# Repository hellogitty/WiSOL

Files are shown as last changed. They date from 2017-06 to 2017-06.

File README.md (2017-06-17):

# WiSOL
Eagle Library, BoB and other moduls and (in near future) demo source codes for WiSOL Sigfox Modules (maybe other repo)

Welcome to the WiSOL Github page made by GREATECH GmbH to support the WSSFM10 Sigfox Modules by WiSOL.<br>
We like to add here (Eagle) CAD library, schematics (eg. BoB Module) and demo projects for different MCUs using the Sigfox modules.
The Library should be fine and ready for production use.
The BoB module is now all metric and vias moved to outside the WiSOL module, so under the module is no via left.
We think vias below the module should be no issue, but anyway.

For purchase you can request price at http://www.greatech.de or order by web shop (soon) http://syncronice.me/products/<br>
A more detailed Wiki we try to build here: http://sensoco.wikidot.com/start

WiSOL is a trademark by WiSOL South Korea<br>
GREATECH, Syncronice and Sensoco are trademark by GREATECH GmbH Germany

**GREATECH GmbH**<br>
Lindenstr. 66A<br>
45478 Mülheim an der Ruhr, Germany<br>
USt-ID-Nr.: 	DE230390597<br>
WEEE-Reg.-Nr.: 	DE 39441116<br>
E-Mail: 	info@greatech.de<br>
Telephone: 	+49 (0) 208 - 740 49 27 0<br>
Fax no.: 	+49 (0) 208 - 740 49 27 19<br>
http://www.greatech.de

**WiSOL**<br>
Company 	WISOL Corp<br>
Address 	531-7 Gijang-ro Osan-si Gyeonggi-do<br>
CEO 	 	Kim Ji Ho<br>
TEL 	 	070-7837-2730<br>
FAX 	 	031-378-6340<br>
http://www.wisol.co.kr/2016_company_eng/?ckattempt=1

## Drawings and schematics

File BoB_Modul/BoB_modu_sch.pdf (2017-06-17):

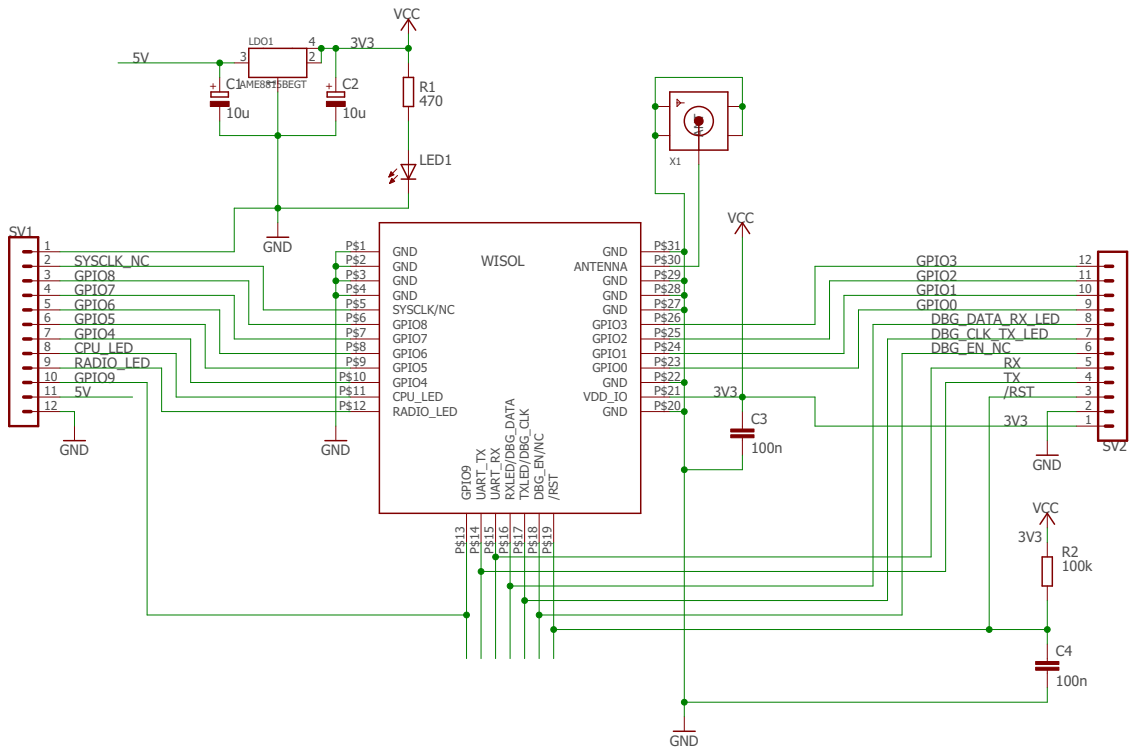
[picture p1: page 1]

P$2 | P$30 GND
P$3 | P$29 ANTENNA
P$4 | P$28 GND
P$5 | P$27 GND

GPIO4 P$10 | 3V3
P$11 | P$21 GND
P$12 | P$20 VDD_IO

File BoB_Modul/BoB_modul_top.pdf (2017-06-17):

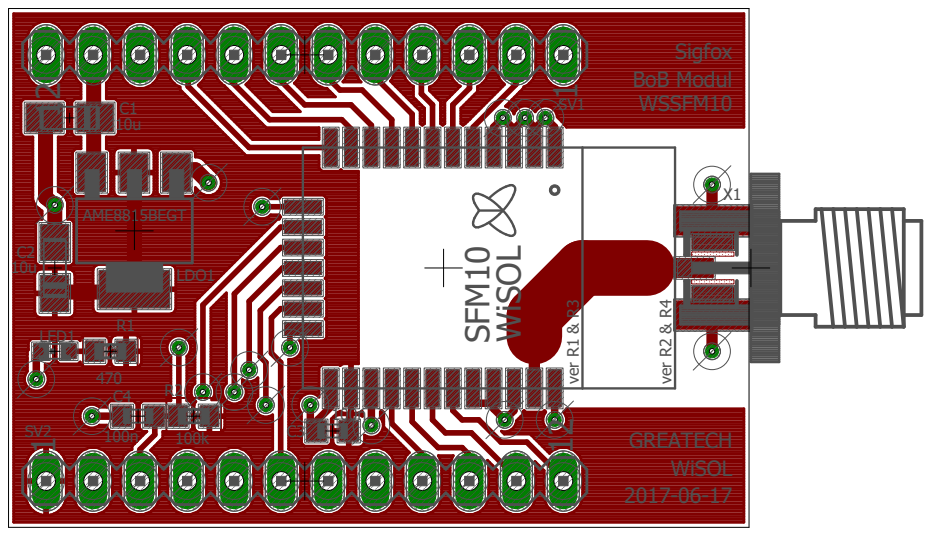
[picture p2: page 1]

WiSOL SFM10 ver R1 & R3 ver R2 & R4 112 112GREATECH Sigfox WiSOL WSSFM10 2017-06-17 BoB ModulX1 SV1 LDO1 C1 C2 R1 LED1 C3 C4 R2 SV2 AME8815BEGT 10u 10u 470 100n 100n 100k

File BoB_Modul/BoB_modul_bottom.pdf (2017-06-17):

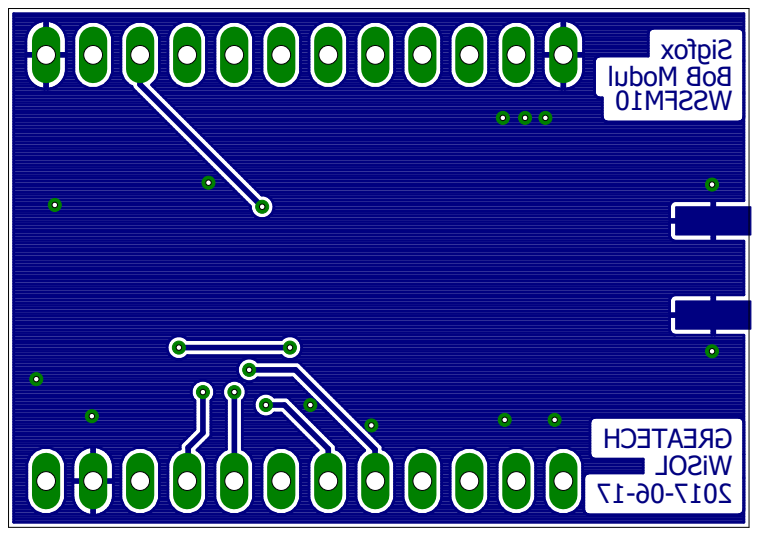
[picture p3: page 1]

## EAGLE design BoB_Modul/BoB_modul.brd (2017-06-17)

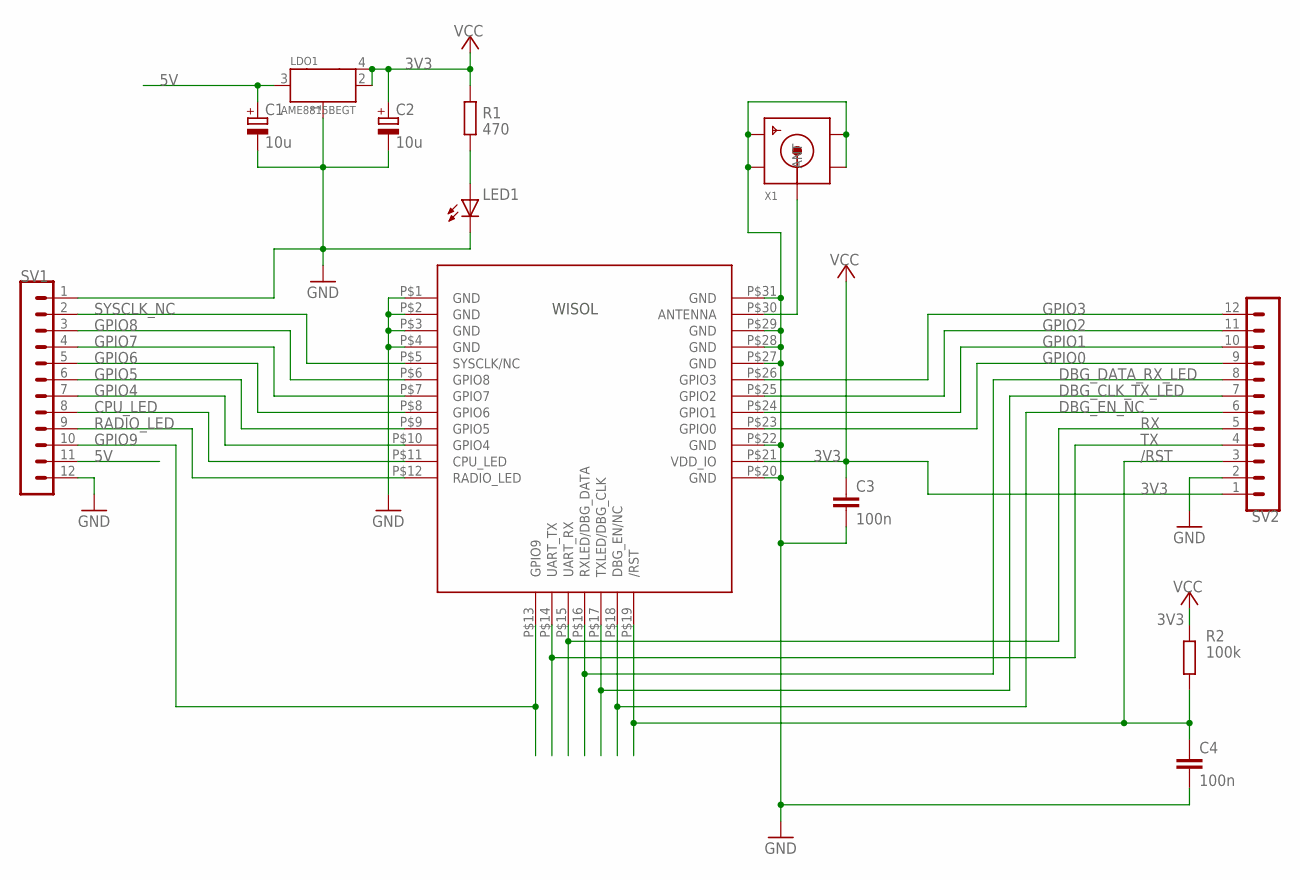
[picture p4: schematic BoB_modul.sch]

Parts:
C1, C2: 10u; A/3216-18R
C3, C4: 100n; C0603K
LDO1: AME8815BEGT; SOT223
LED1: LEDCHIPLED_0603; CHIPLED_0603
R1: 470; R0603
R2: 100k; R0603
SV1, SV2: MA12-1
WSSFM10: SFM10; WSSFM10
X1: SMACONNECTOR_EDGE_UFL; SMA_EDGELAUNCH_UFL

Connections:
3V3: C2.+, C3.1, LDO1.2, LDO1.4, R1.2, R2.2, SV2.1, WSSFM10.P$21 (VDD_IO)
5V: C1.+, LDO1.3, SV1.11
/RST: C4.1, R2.1, SV2.3, WSSFM10.P$19 (/RST)
CPU_LED: SV1.8, WSSFM10.P$11 (CPU_LED)
DBG_CLK_TX_LED: SV2.7, WSSFM10.P$17 (TXLED/DBG_CLK)
DBG_DATA_RX_LED: SV2.8, WSSFM10.P$16 (RXLED/DBG_DATA)
DBG_EN_NC: SV2.6, WSSFM10.P$18 (DBG_EN/NC)
GND: C1.-, C2.-, C3.2, C4.2, LDO1.1, LED1.C, SV1.1, SV1.12, SV2.2, WSSFM10.P$1 (GND), WSSFM10.P$2 (GND), WSSFM10.P$3 (GND), WSSFM10.P$4 (GND), WSSFM10.P$20 (GND), WSSFM10.P$22 (GND), WSSFM10.P$27 (GND), WSSFM10.P$28 (GND), WSSFM10.P$29 (GND), WSSFM10.P$31 (GND), X1.GND@1 (GND1), X1.GND@2 (GND2), X1.GND@3 (GND3), X1.GND@4 (GND4)
GPIO0: SV2.9, WSSFM10.P$23 (GPIO0)
GPIO1: SV2.10, WSSFM10.P$24 (GPIO1)
GPIO2: SV2.11, WSSFM10.P$25 (GPIO2)
GPIO3: SV2.12, WSSFM10.P$26 (GPIO3)
GPIO4: SV1.7, WSSFM10.P$10 (GPIO4)
GPIO5: SV1.6, WSSFM10.P$9 (GPIO5)
GPIO6: SV1.5, WSSFM10.P$8 (GPIO6)
GPIO7: SV1.4, WSSFM10.P$7 (GPIO7)
GPIO8: SV1.3, WSSFM10.P$6 (GPIO8)
GPIO9: SV1.10, WSSFM10.P$13 (GPIO9)
unnamed: LED1.A, R1.1
unnamed: WSSFM10.P$30 (ANTENNA), X1.P (ANT)
RADIO_LED: SV1.9, WSSFM10.P$12 (RADIO_LED)
RX: SV2.5, WSSFM10.P$15 (UART_RX)
SYSCLK_NC: SV1.2, WSSFM10.P$5 (SYSCLK/NC)
TX: SV2.4, WSSFM10.P$14 (UART_TX)

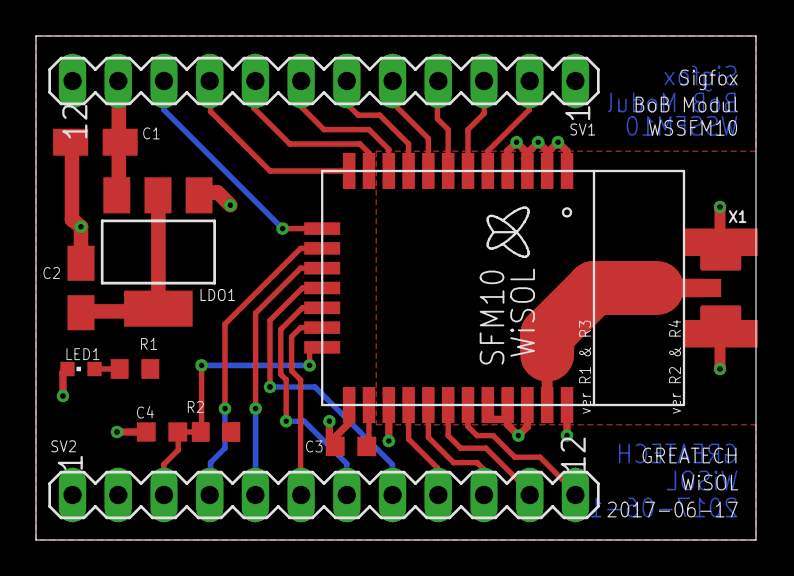
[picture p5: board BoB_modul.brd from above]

Board: 2 copper layers, 40.0 x 28.0 mm, 12 parts (0 on the bottom side), 24 nets.

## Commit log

2017-05-21 Library updated + BoB-Module sch + brd created
    [BoB_modul.brd, BoB_modul.sch]
2017-06-17 make metric and nice, not yet finnished, work in progress
    [BoB_modul.brd]
2017-06-17 make metric, moved vias out of WiSOL module, ready fro production
    [BoB_modul.brd]
2017-06-17 Gerber and Drill data produced
